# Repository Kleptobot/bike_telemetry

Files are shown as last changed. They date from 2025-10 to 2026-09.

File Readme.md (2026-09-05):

# OBike — Open Bicycle Telemetry Platform

OBike is an open-source hardware and firmware project for building a DIY bike computer that feels closer to a purpose-built cycling device than a generic microcontroller project. It combines a colour display, GPS, Bluetooth sensors, barometric altitude, and SD-card logging into a single platform you can build, modify, and improve.

If you like the idea of a compact, open bike computer that can log rides, display live metrics, and be extended with new sensors or UI ideas, this repository is a good place to start.

OBike v3 assembly

## What this project does

OBike is intended to capture and present ride data such as:

- speed and distance
- cadence and power
- heart rate
- GPS position and track history
- barometric altitude and sensor-derived data

It presents that information on a colour screen and can log sessions to microSD in FIT, TCX, or CSV formats.

It also supports common Bluetooth cycling peripherals that implement the CSC, HRM, and CPS profiles.

## What is in this repository

- `src/` — firmware source in C++
  - `src/App.*` — main application state and control flow
  - `src/HAL/` — hardware abstraction for GPS, SD, Bluetooth, buttons, and sensors
  - `src/ui/` — UI screens and widgets
  - `src/Loggers/` — FIT, TCX, and CSV logging implementations
  - `src/display/` — display driver and rendering wrappers
- `kicad/` — KiCad schematic and PCB layout files
- `3D_CAD/` — enclosure and mounting CAD files for 3D printing
- `sim/` — desktop simulator for trying the firmware logic without hardware
- `platformio.ini` — PlatformIO build configuration

## Hardware overview

The current hardware target is a compact embedded bike-computer build based on:

- MCU: Seeed Studio XIAO nRF52840 (Sense)
- GNSS: Quectel LC76G module
- Display: ST7789-based full-colour 240×320 SPI panel
- Sensors: RTC, barometric pressure sensor, IMU, and SD card storage
- IO: debounced physical controls and Bluetooth cycling-device support

## Quick start

### Build the firmware

1. Install PlatformIO.
2. From the repository root, run:

   ```bash
   platformio run
   ```

3. To upload to the target board:

   ```bash
   platformio run --target upload
   ```

### Try it without hardware

The repository includes a desktop simulator under `sim/` that can exercise much of the application logic and UI without needing the embedded board.

## Software features

- Firmware built with PlatformIO and the Arduino framework
- Telemetry aggregation from BLE sensors, GPS, and onboard sensors
- Logging to microSD in FIT, TCX, and CSV formats
- GPS control and NMEA handling for the LC76G module
- A simple UI for ride data and device interaction
- Bluetooth device discovery, pairing, and connection management

## Dependencies

The firmware depends on a number of Arduino and embedded libraries, including:

- `Adafruit_GFX`
- `Adafruit_ST7789`
- `RTClib`
- `MCP23017` support for the I/O expander
- `LSM6DS3`
- `XENSIV` pressure-sensor support
- `ArduinoJson`
- `TinyGPSPlus`

## Key files to inspect

- `src/HAL/LC76G.cpp` and `src/HAL/LC76G.hpp` — GNSS driver, NMEA handling, and command flow
- `src/display/Display.hpp` and `src/display/Display.cpp` — display wrapper and rendering layer
- `src/Loggers/TCXLogger.cpp` and `src/Loggers/CSVLogger.cpp` — ride logging implementations
- `src/App.cpp` — main application loop and state handling
- `kicad/` — schematic and PCB design files
- `3D_CAD/` — printable enclosure and mounting hardware

## Troubleshooting and debugging

- Serial logs are useful during development and can help trace GPS and device activity.
- Raw NMEA data can be captured to the SD card for debugging GPS behavior.
- The LC76G path has previously been sensitive to malformed or long NMEA streams, so keeping firmware updates current is important if you hit GPS issues.

## Notes for first-time visitors

This project is best viewed as a hands-on, open-source bike-computer platform rather than a polished consumer product. It is a strong fit if you want to learn embedded firmware, PCB design, logging formats, BLE peripherals, and how a compact cycling computer can be assembled from open parts.

If you are curious about building your own ride-data device, this repository is a practical starting point for both the hardware and software sides of the project.

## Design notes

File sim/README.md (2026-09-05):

# OBike simulator

Runs the OBike firmware on a desktop. The UI you see is drawn by the real
`Adafruit_GFX` through the real widgets — not a mock-up — so it can be used
both for UI development and for exercising application logic.

## What is real and what is simulated

Only **two** firmware translation units are replaced:

| Replaced | Why |
|---|---|
| `src/HAL/HAL.cpp` → `host/SimHAL.cpp` | supplies simulated sensor values |
| `src/HAL/LC76G.cpp` → `host/SimLC76G.cpp` | I2C GNSS transport has no meaning on a host |

Everything else is compiled from the real source and runs unmodified:

- all of `App`, `DataModel`, `Loggers`, `Map`, `Fusion` and `ui`
- `InputSystem` — including the real `button` edge/hold/repeat logic
- `Sensors`, `SDCard`, and the whole `Fusion` layer (altitude fusion, speed
  selection, grade, distance) — the simulated barometer is driven from the
  scenario altitude, so the real estimator computes what the tiles show
- the entire Bluetooth stack, **including the CSC/CPS/HRM measurement parsers**

The vendored libraries (`Adafruit_GFX`, `ArduinoJson`, `TinyGPSPlus`) are linked
straight out of `.pio/libdeps`, not copied, so the simulator cannot drift from
the firmware build.

GPS is driven by generating **real NMEA sentences** (with correct checksums) and
feeding them through the real `TinyGPSPlus`, so fix acquisition, speed and
altitude age all exercise the production code path.

## Quick start

One prerequisite: run `pio run` in the repo root once, so `.pio/libdeps` exists
— the simulator links the same library sources the firmware does.

**Windows** (cmd.exe, PowerShell, or just double-click `run.bat`):

```
cd sim
.
un.bat --headless --frames 30 --out out
python tools\ppm2png.py out --scale 2
```

Note the leading `.\` — PowerShell does not run programs from the current
directory without it. In cmd.exe plain `run.bat` is fine.

**Git Bash / Linux / macOS:**

```
cd sim
./run.sh --headless --frames 30 --out out
python3 tools/ppm2png.py out --scale 2
```

Then open `out/frame_0029.png`.

Both launchers build if needed and locate the compiler themselves, so nothing
has to be added to PATH. If you would rather drive make directly:

```
mingw32-make            # SDL window if SDL2 is available
mingw32-make headless   # force the no-SDL build
mingw32-make run
```

Note the Makefile recipes use `mkdir -p` and `rm -rf`; `run.bat` puts Git for
Windows' `usrin` on PATH so those exist under cmd.exe.

## Run

```
run.bat                                     # interactive window (needs SDL2)
run.bat --headless --frames 200 --out out   # frame dump, no dependencies
```

Frames are RGB565 PPM, which most image viewers will not open.
`tools/ppm2png.py` converts them using only `zlib` and `struct` from the
standard library, so no Pillow install is needed. `--gif out/ride.gif` also
writes an animation — that one path does want Pillow.

## Toolchain

If the launcher reports no compiler:

```
winget install BrechtSanders.WinLibs.POSIX.UCRT
```

## SDL2 (optional, for the interactive window)

```
tools\get-sdl2.bat          # Windows
tools/get-sdl2.sh           # Git Bash / Linux / macOS
```

Downloads the SDL2 MinGW SDK into `third_party/` and drops the 32-bit half,
leaving about 60 MB. **`third_party/` is gitignored** — it is a platform
specific binary SDK, and the repo links third-party sources rather than
vendoring them, the same way `Adafruit_GFX` comes from `.pio/libdeps`.

Without SDL2 the build falls back to headless automatically and still runs and
writes frames; only the window and keyboard input are missing. `SDL2.dll` is
copied next to the binary at build time, so nothing needs to be on PATH.

| Flag | Meaning |
|---|---|
| `--headless` | no window |
| `--frames N` | headless frame count |
| `--step MS` | simulated milliseconds per frame |
| `--out DIR` | write RGB565 frames as PPM |
| `--scale N` | SDL window scale |
| `--sd DIR` | SD card root (default `./sdcard`) |

Keys: arrows = D-pad, Enter/Space = select, `S` toggles the SD card, `G` toggles
the GPS fix, `[` / `]` change speed, Esc quits.

## Simulated time

`millis()` is a counter the frontend advances, not the wall clock. A headless
run is therefore fully deterministic and can be stepped in a debugger, and a
scenario can run faster than real time. `delay()` advances the counter rather
than sleeping.

## Sample card contents

`sample-sd/` holds a starting configuration, copied into `sdcard/` on first run
(never overwriting an existing one, so anything you change in the simulator
survives):

| File | What it gives you |
|---|---|
| `layout.txt` | a 2x3 tile grid: full-width Speed, then Cadence/HeartRate and Power/TotalDist |
| `bikeStats.txt` | 2105 mm wheel circumference -- without this the wheel-speed path computes exactly 0 |
| `biometrics.txt` | mass and HR zones, so the heart-rate tile colours correctly |
| `time.txt` | UTC offset 0 |

To start clean, delete `sdcard/` and run again. To keep several
configurations, copy them elsewhere and use `--sd DIR`.

## The SD card is a real directory

`./sdcard/` backs `IStorage`, so `layout.txt`, `biometrics.txt` and
`devices.txt` behave exactly as on the device — and a simulated ride writes a
genuine `.fit` file you can open in Garmin Connect, Strava or the FIT SDK.
That is a considerably stronger check on the logger than any assertion.

## Injecting BLE measurements

`Sim::buildCpsMeasurement()` and friends construct spec-shaped payloads;
`Sim::injectCpsNotification()` hands them to the real parser. Useful for
checking power/cadence decoding without a sensor.

## Simulated sensors

The sim can run the whole sensor story -- pairing, discovery, notification
decoding, baselining and the RPM smoothing filters -- with no radio:

- At init the card is seeded with a `devices.txt` fixture (three sensors:
  wheel, power, heart rate) unless one is already present, so the firmware's
  real `loadDevices()` path creates the parser devices at App BOOT.
- ~1.5 s of simulated time in, each device's real `discover()` runs against
  the stub radio and the stub connection handles are aligned.
- `HAL::update()` then feeds spec-shaped notifications into the parsers at
  the ~1 Hz cadence real sensors use, whenever the scenario says a sensor is
  present (`wheelRPMLive`, `power > 0`, `heartRate > 0`).

`--sensors` starts a headless run with all three sensors live at riding
values (24 km/h, 85 rpm, 180 W, 132 bpm). Interactively, `]` brings the
wheel sensor up as before. Values reaching the UI, the fusion engine and the
loggers have been decoded by the unmodified firmware parsers.

Note the ramp-in: the CSC parsers low-pass their revolution-derived estimates
with a ~1000-update time constant, so wheel speed and cadence climb toward
the scenario values over roughly 20-30 s of simulated time -- the same
behaviour you see on hardware after pairing. Power and heart rate decode
immediately. For a converged headless run use a longer frame count, e.g.
`--headless --sensors --frames 4000`.

## Headless navigation and telemetry

Headless runs can also navigate the UI and report what the app published:

```
./build/obike-sim --headless --sensors --stats --frames 1200 --last 2 \
                  --screen BikeStats --out out
```

- `--sensors` starts the run with all three sensors paired and live
- `--stats` prints the published telemetry every 250 frames -- a numeric
  trace of exactly what the app derived from the injected data
- `--screen NAME` navigates once boot completes (BikeStats, Settings,
  Bluetooth, Biometrics, GPS, Time, Display, UnmountSD, MainMenu)
- `--last N` writes only the final N PPM frames of the run

## Relationship to unit tests

The `stubs/` directory is the same substrate a native test build needs. A test
target reuses `stubs/` and the host `IStorage`, drops `host/main.cpp` and the
UI sources, and adds a test runner. The expensive part — the Arduino and
hardware stubs — is already done.

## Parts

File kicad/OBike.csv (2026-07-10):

Reference | Value | Footprint | MANUFACTURER | Digikey PN | Qty
C1,C3,C11,C13 | 0.1uF | Capacitor_SMD:C_0805_2012Metric | Samsung | 1276-2442-1-ND | 4
C2,C4,C5,C6,C7,C8,C9,C12,C14 | 1.0uF | Capacitor_SMD:C_0805_2012Metric | Samsung | 1276-1066-1-ND | 9
C10,C19 | 10uF | Capacitor_SMD:C_0603_1608Metric | Samsung | 1276-1038-1-ND | 2
C16,C21 | 33pF | Capacitor_SMD:C_0603_1608Metric | KEMET | 399-C0603C330K3RACTUCT-ND | 2
C17,C20 | 100nF | Capacitor_SMD:C_0603_1608Metric | KEMET | 399-C0603C104K3RACTUCT-ND | 2
C18 | 4.7uF | Capacitor_SMD:C_0603_1608Metric | Samsung | 1276-1044-1-ND | 1
D1,D2,D3,D4,D5 | 1N4148W | Diode_SMD:D_SOD-123 | SMC Diode Solutions | 1655-1N4148WCT-ND | 5
D6,D7 | ESDA051-1JY | Diode_SMD:D_SOD-323 | STMicroelectronics | 497-ESDA051-1JYCT-ND | 2
J1 | F34G-1A7Q1-E8C40 | amphenol:AMPHENOL_F34G-1A7Q1-E8C40 | Amphenol | 609-F34G-1A7Q1-E8C40CT-ND | 1
J2 | Micro_SD_Card_Det1 | CUI:CUI_MSD-4-A | Same Sky | 2223-MSD-4-ACT-ND | 1
J3 | Conn_01x02 | Connector_JST:JST_PH_S2B-PH-K_1x02_P2.00mm_Horizontal | JST | 455-1719-ND | 1
J5 | U.FL-R-SMT-1_10_ | Hirose:HRS_U.FL-R-SMT-1_10_ | Hirose | H11891CT-ND | 1
Q1,Q2 | SS8050 | Package_TO_SOT_SMD:SOT-23 | MCC | MMSS8550-H-TPMSCT-ND | 2
R1,R2,R3,R4,R5,R6,R7,R8,R9,R10,R22,R23,R24,R25 | 10K | Resistor_SMD:R_0805_2012Metric |  | RMCF0805JT10K0CT-ND | 14
R11,R16,R17 | 100K | Resistor_SMD:R_0603_1608Metric |  | RMCF0603FT100KCT-ND | 3
R12 | 2R2 | Resistor_SMD:R_0603_1608Metric |  | RMCF0603FT2R20CT-ND | 1
R15,R38 | 1K | Resistor_SMD:R_0603_1608Metric |  | RMCF0603JT1K00CT-ND | 2
R18,R37 | 10K | Resistor_SMD:R_0603_1608Metric |  | RMCF0603JT10K0CT-ND | 2
R36 | 47R | Resistor_SMD:R_0603_1608Metric |  | RMCF0805JT10K0CT-ND | 1
SW1 | 5_position_tactile | 5_pos:5-position | TE Connectivity | 450-2425755-1CT-ND | 1
U1 | DPS368XTSA1 | Infineon Technologies:PG-VLGA-8-2_INF | Infineon Technologies | DPS368XTSA1CT-ND | 1
U2 | DS3231M | Package_SO:SOIC-8_3.9x4.9mm_P1.27mm | Analog Devices Inc | DS3231MZ+-ND | 1
U3 | MCP23017_SO | Package_SO:SOIC-28W_7.5x17.9mm_P1.27mm | Microchip | MCP23017T-E/SOCT-ND | 1
U4 | 74HC14 | Package_SO:SOIC-14_3.9x8.7mm_P1.27mm | Toshiba Semiconductor | 74HC14DCT-ND | 1
U6,U8,U10 | MAX40200AUK | Package_TO_SOT_SMD:SOT-23-5 | Analog Devices Inc | MAX40200AUK+TCT-ND | 3
U7 | LC76G | quectel:XCVR_LC76G | Quectel | 2958-LC76GPAMDCT-ND | 1
U9 | W25N01GVZEIG_TR | windbond:SON127P800X600X80-9N | Winbond Electronics | 256-W25N01GVZEIGTRCT-ND | 1
LS1 | ASI09N40MTRQ | Mallory:ASI09N40M | Mallory | 458-ASI09N40MTRQCT-ND | 1

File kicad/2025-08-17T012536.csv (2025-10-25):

Index | Quantity | Part Number | Manufacturer Part Number | Description | Customer Reference | Available | Backorder | Unit Price | Extended Price AUD
1 | 10 | 1276-1038-1-ND | CL10A106KQ8NNNC | CAP CER 10UF 6.3V X5R 0603 |  | 10 | 0 | 0.03800 | 0.38
2 | 10 | 399-C0603C330K3RACTUCT-ND | C0603C330K3RACTU | CAP CER 33PF 25V X7R 0603 |  | 10 | 0 | 0.20500 | 2.05
3 | 10 | 399-C0603C104K3RACTUCT-ND | C0603C104K3RACTU | CAP CER 0.1UF 25V X7R 0603 |  | 10 | 0 | 0.04100 | 0.41
4 | 15 | 1655-1N4148WCT-ND | 1N4148W | DIODE GEN PURP 75V 250MA SOD123 |  | 15 | 0 | 0.12300 | 1.85
5 | 10 | 1727-2742-1-ND | PTVS5V0Z1USKYL | TVS DIODE 5VWM 12VC DSN1608-2 |  | 10 | 0 | 0.11100 | 1.11
6 | 3 | 609-1200-1-ND | 62684-402100ALF | CONN FPC TOP 40POS 0.5MM R/A |  | 3 | 0 | 0.95000 | 2.85
7 | 3 | 2223-MSD-4-ACT-ND | MSD-4-A | CONN MICROSD CARD R/A SMD |  | 3 | 0 | 0.57000 | 1.71
8 | 3 | H11891CT-ND | U.FL-R-SMT-1(10) | CONN U.FL RCPT STR 50 OHM SMD |  | 3 | 0 | 1.91000 | 5.73
9 | 50 | RMCF0603FT100KCT-ND | RMCF0603FT100K | RES 100K OHM 1% 1/10W 0603 |  | 50 | 0 | 0.01820 | 0.91
10 | 50 | RMCF0603FT2R20CT-ND | RMCF0603FT2R20 | RES 2.2 OHM 1% 1/10W 0603 |  | 50 | 0 | 0.01020 | 0.51
11 | 2 | 2958-LC76GPAMDCT-ND | LC76GPAMD | RF TXRX MODULE NAVIGATION SMD |  | 2 | 0 | 13.18000 | 26.36
12 | 2 | 256-W25N01GVZEIGTRCT-ND | W25N01GVZEIG TR | IC FLASH 1GBIT SPI 104MHZ 8WSON |  | 2 | 0 | 5.76000 | 11.52
13 | 3 | MAX40200AUK+TCT-ND | MAX40200AUK+T | IC DIODE CURRENT SWITCH SOT23-5 |  | 3 | 0 | 2.04000 | 6.12
14 | 10 | 1276-1044-1-ND | CL10A475KP8NNNC | CAP CER 4.7UF 10V X5R 0603 |  | 10 | 0 | 0.01000 | 0.10

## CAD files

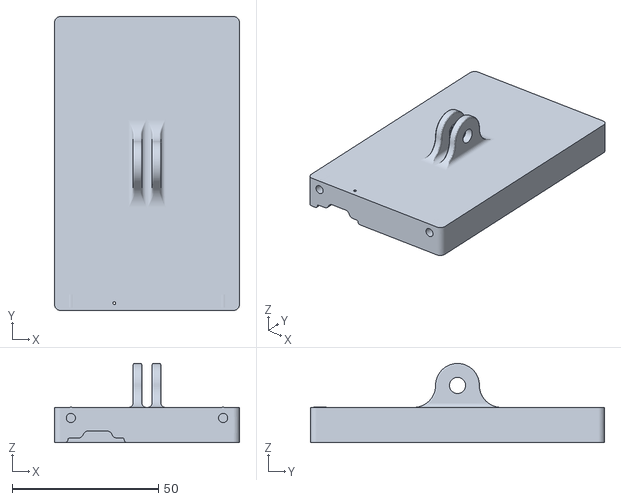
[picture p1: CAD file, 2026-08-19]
3D_CAD/back_retainer_combo.stl
63.2 x 100.4 x 27.0

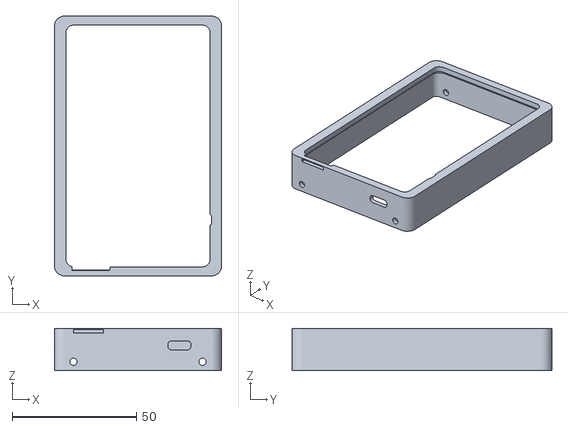
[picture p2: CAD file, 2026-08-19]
3D_CAD/housing.stl
67.4 x 104.6 x 16.9

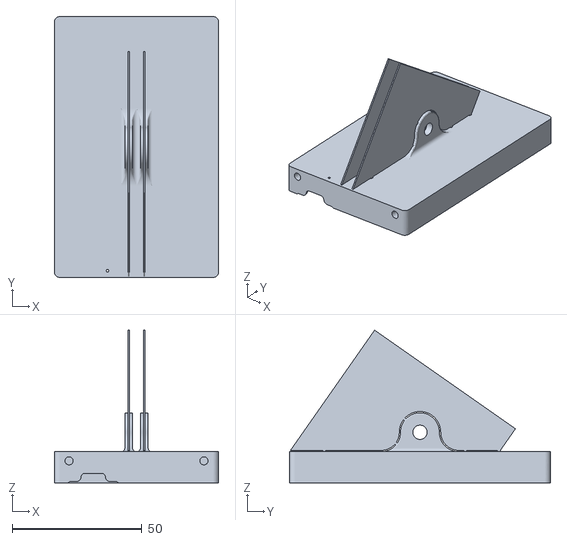
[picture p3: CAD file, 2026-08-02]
3D_CAD/back_retainer_combo + support.stl
63.4 x 100.7 x 58.9

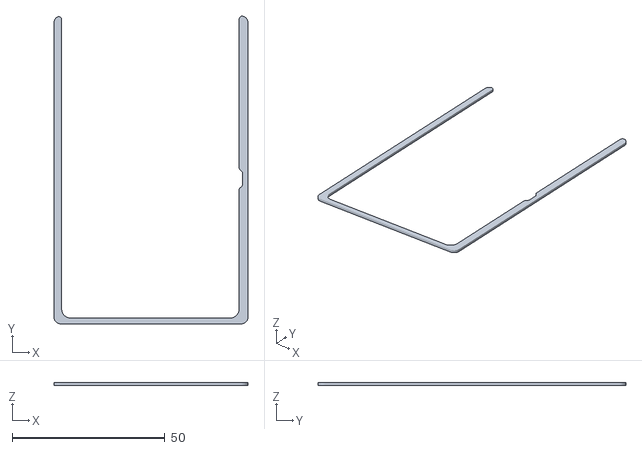
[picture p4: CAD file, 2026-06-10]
3D_CAD/shim.stl
63.4 x 100.6 x 1.00

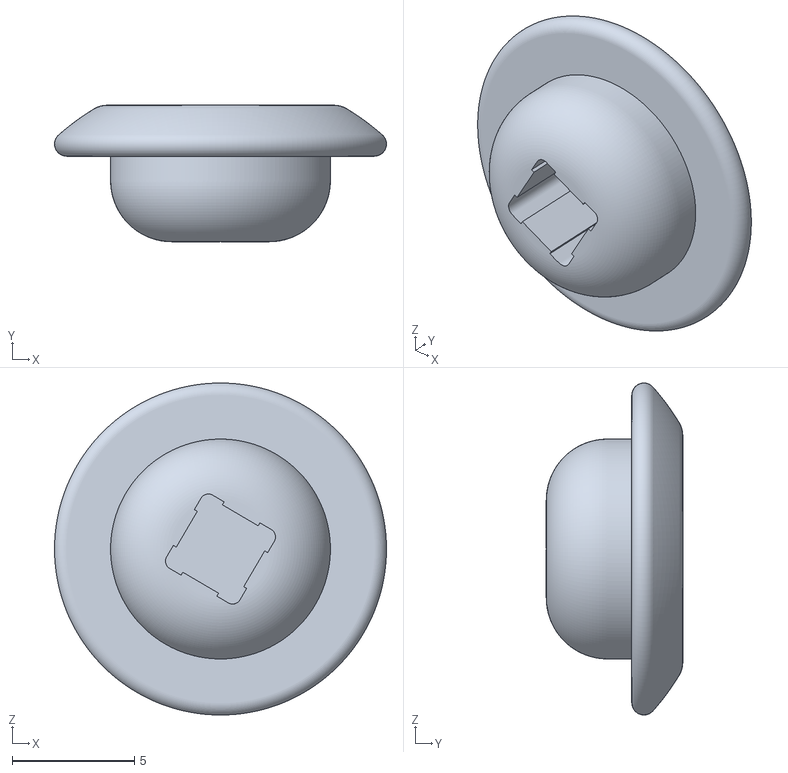
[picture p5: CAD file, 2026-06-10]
3D_CAD/nubbin.stl
13.6 x 5.59 x 13.6

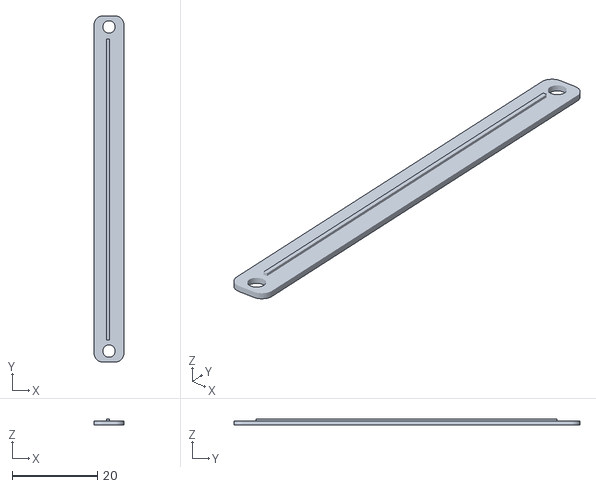
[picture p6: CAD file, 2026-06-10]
3D_CAD/battery_strap.stl
7.00 x 81.3 x 1.50

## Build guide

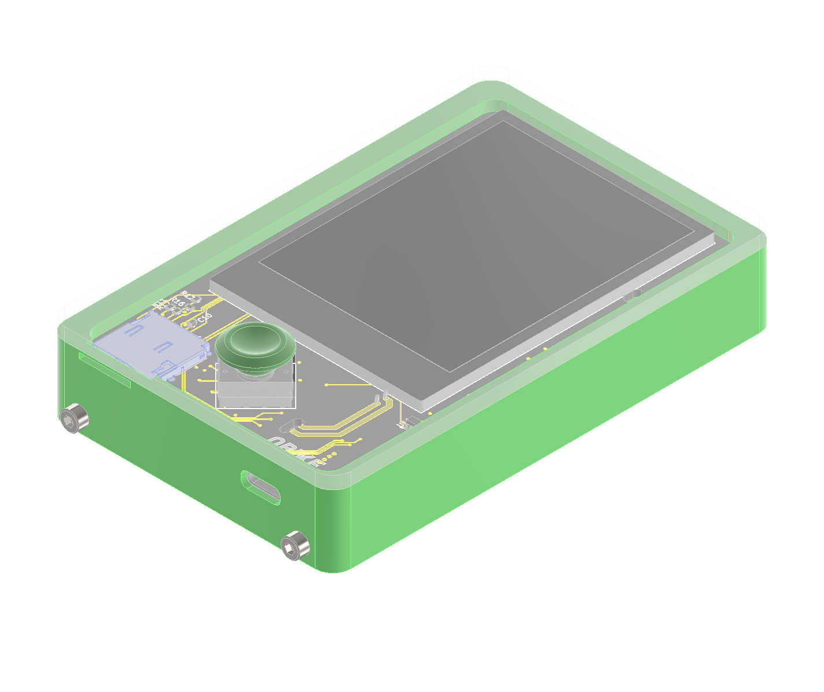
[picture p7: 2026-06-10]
3D_CAD/OBike v3 assembly.png

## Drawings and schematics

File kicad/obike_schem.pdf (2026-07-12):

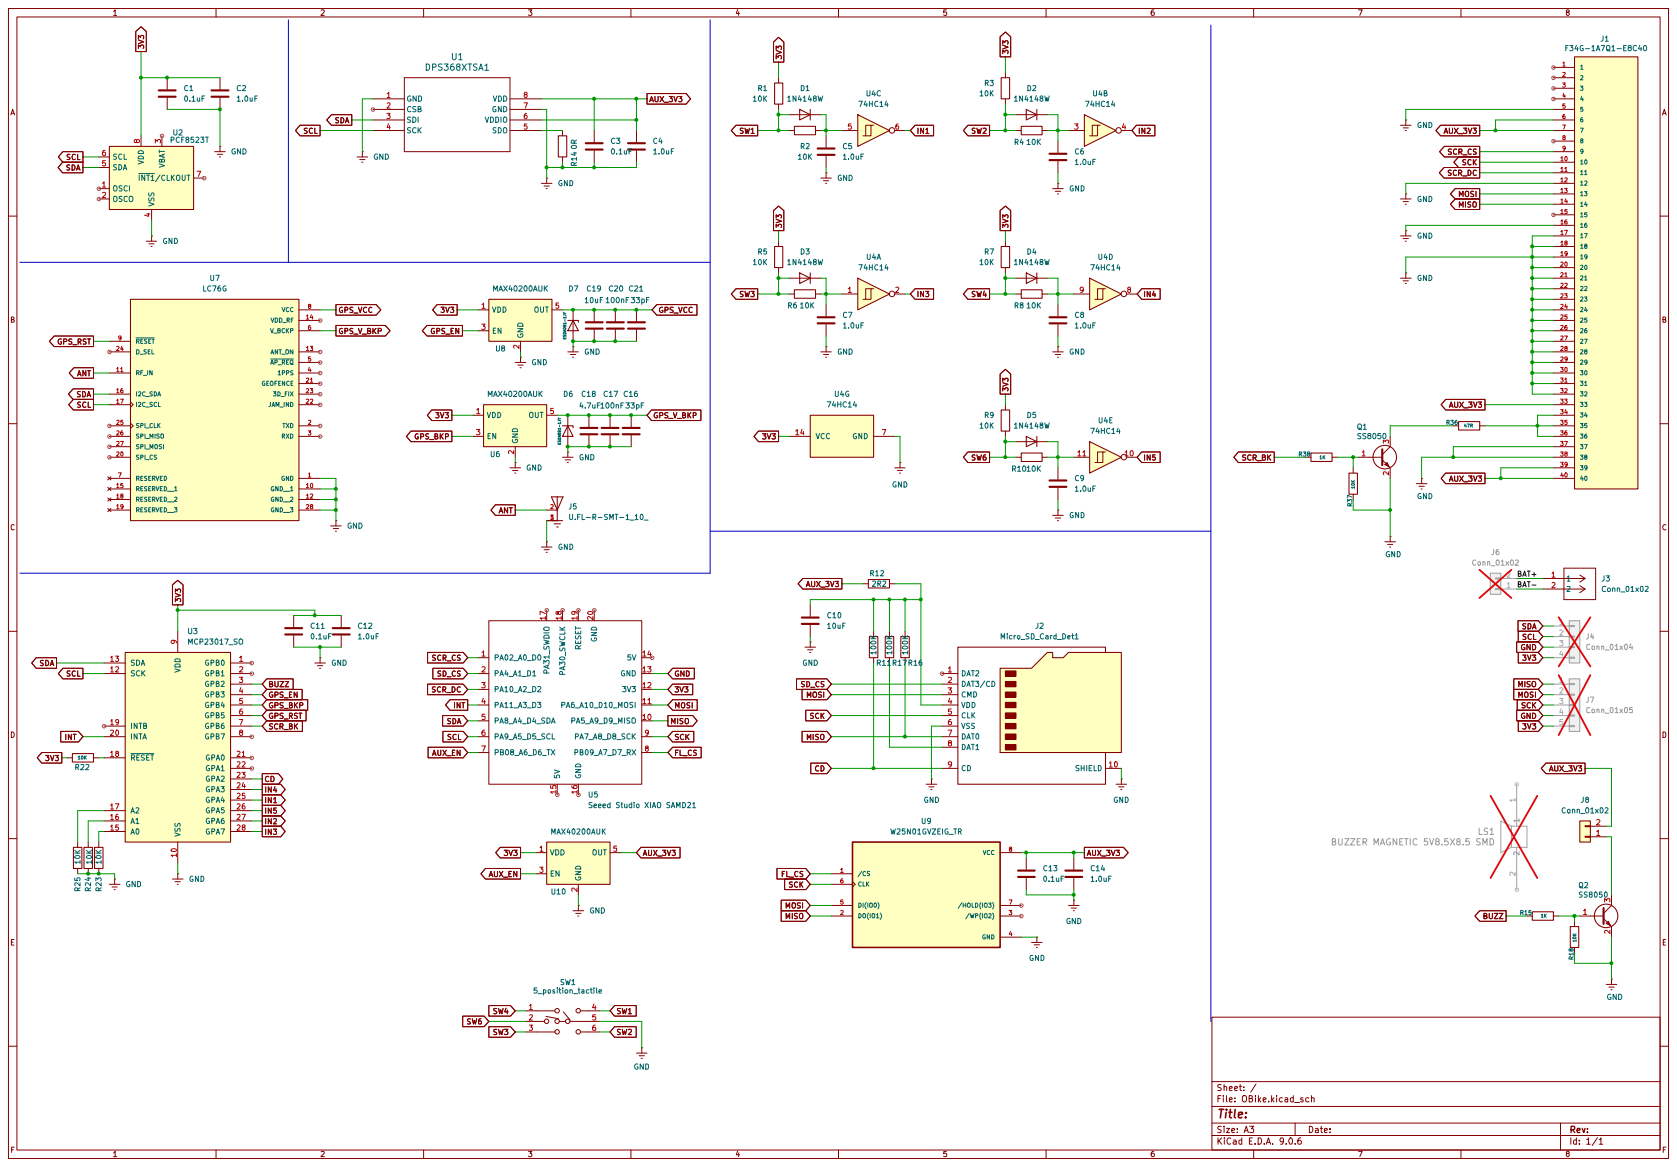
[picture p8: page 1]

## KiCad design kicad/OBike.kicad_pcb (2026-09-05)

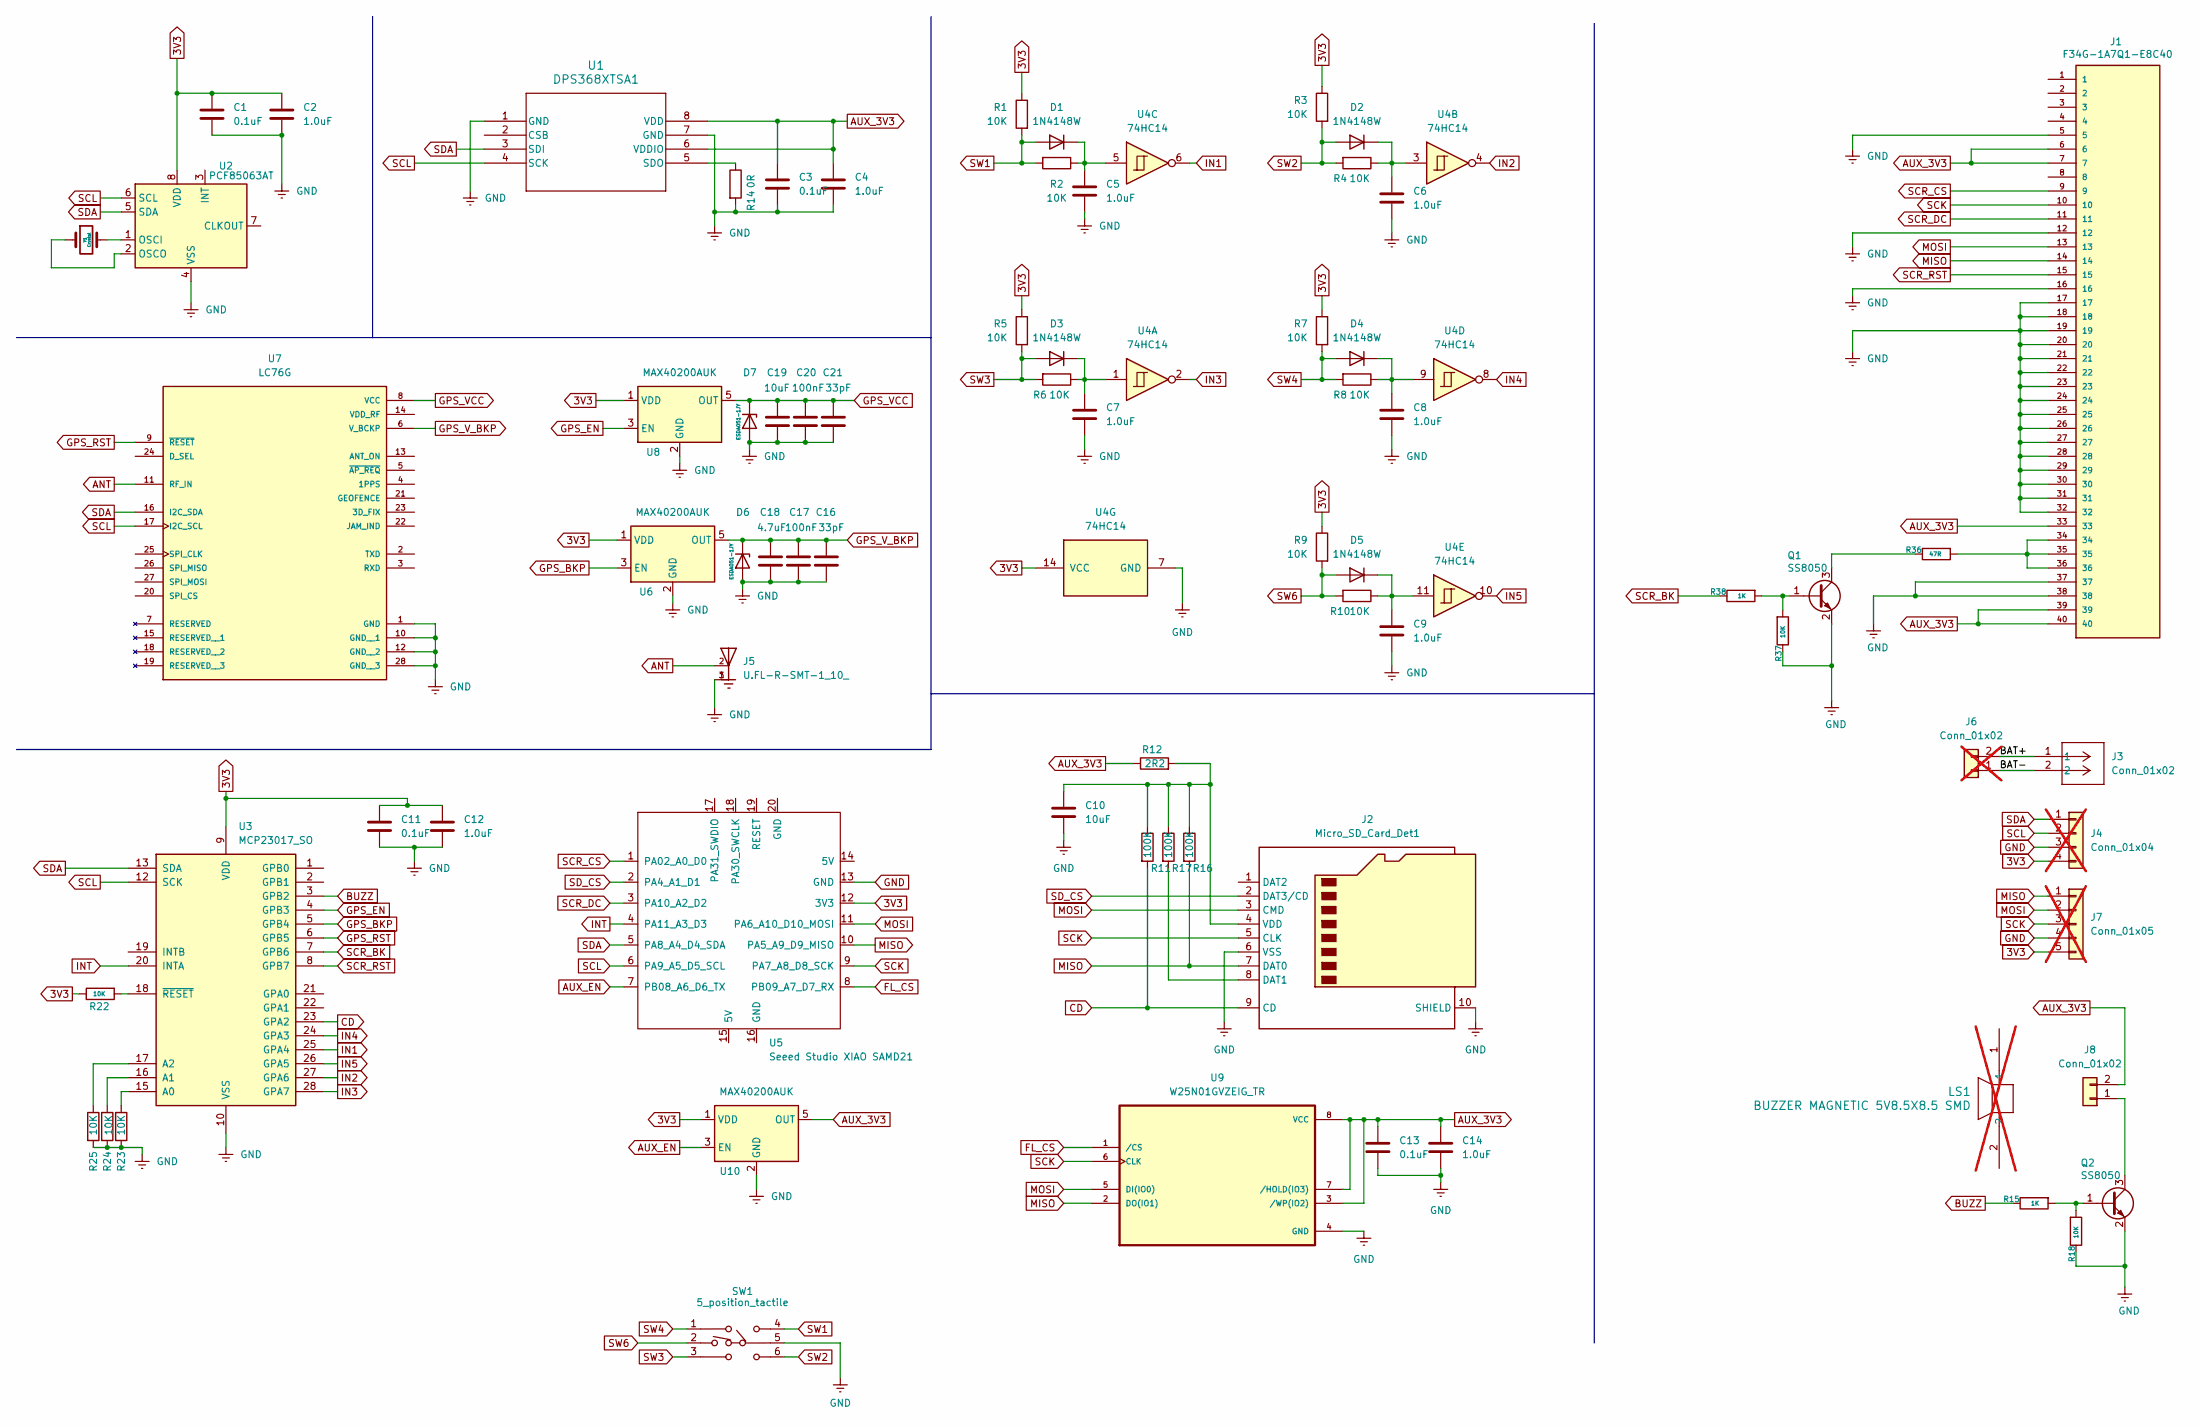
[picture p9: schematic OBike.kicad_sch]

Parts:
C1, C3, C11, C13: 0.1uF; C_0805_2012Metric; Digikey PN 1276-2442-1-ND
C2, C4, C5, C6, C7, C8, C9, C12, C14: 1.0uF; C_0805_2012Metric; Digikey PN 1276-1066-1-ND
C10, C19: 10uF; C_0603_1608Metric; Digikey PN 1276-1038-1-ND
C16, C21: 33pF; C_0603_1608Metric; Digikey PN 399-C0603C330K3RACTUCT-ND
C17, C20: 100nF; C_0603_1608Metric; Digikey PN 399-C0603C104K3RACTUCT-ND
C18: 4.7uF; C_0603_1608Metric; Digikey PN 1276-1044-1-ND
D1, D2, D3, D4, D5: 1N4148W; D_SOD-123; Manufacturer PN 1N4148W RHG; Digikey PN 1655-1N4148WCT-ND
D6, D7: ESDA051-1JY; D_SOD-323; Digikey PN 497-ESDA051-1JYCT-ND
J1: F34G-1A7Q1-E8C40; AMPHENOL_F34G-1A7Q1-E8C40; PARTREV A; Digikey PN 609-F34G-1A7Q1-E8C40CT-ND
J2: Micro_SD_Card_Det1; CUI_MSD-4-A; Manufacturer PN MSD-4-A; Digikey PN 2223-MSD-4-ACT-ND
J3: Conn_01x02; JST_PH_S2B-PH-K_1x02_P2.00mm_Horizontal; Manufacturer PN CONN HEADER R/A 2POS 2MM; Digikey PN 455-1719-ND
J4: Conn_01x04; PinHeader_1x04_P2.54mm_Vertical; not fitted
J5: U.FL-R-SMT-1_10_; HRS_U.FL-R-SMT-1_10_; Digikey PN H11891CT-ND
J6: Conn_01x02; PinHeader_1x02_P2.00mm_Vertical; not fitted
J7: Conn_01x05; PinHeader_1x05_P2.54mm_Vertical; not fitted
J8: Conn_01x02; PinHeader_1x02_P2.00mm_Vertical
LS1: BUZZER MAGNETIC 5V8.5X8.5 SMD; CUI_CMT-8540S-SMT; Digikey PN 102-3746-1-ND; not fitted
Q1, Q2: SS8050; SOT-23; Digikey PN MMSS8050-H-TPMSCT-ND
R1, R2, R3, R4, R5, R6, R7, R8, R9, R10, R22, R23, R24, R25: 10K; R_0805_2012Metric; Digikey PN RMCF0805JT10K0CT-ND
R11, R16, R17: 100K; R_0603_1608Metric; Digikey PN RMCF0603FT100KCT-ND
R12: 2R2; R_0603_1608Metric; Digikey PN RMCF0603FT2R20CT-ND
R14: 0R; R_0603_1608Metric
R15, R38: 1K; R_0603_1608Metric; Digikey PN RMCF0603JT1K00CT-ND
R18, R37: 10K; R_0603_1608Metric; Digikey PN RMCF0603JT10K0CT-ND
R36: 47R; R_0603_1608Metric; Digikey PN RMCF0603JT47R0CT-ND
SW1: 5_position_tactile; 5-position; Manufacturer PN 2425755-1; Digikey PN 450-2425755-1CT-ND
U1: DPS368XTSA1; PG-VLGA-8-2_INF; Manufacturer PN DPS368XTSA1; Digikey PN DPS368XTSA1CT-ND
U2: PCF85063AT; SOIC-8_3.9x4.9mm_P1.27mm; Digikey PN 568-12403-1-ND
U3: MCP23017_SO; SOIC-28W_7.5x17.9mm_P1.27mm; Manufacturer PN MCP23017T-E/SO; Digikey PN MCP23017T-E/SOCT-ND
U4: 74HC14; SOIC-14_3.9x8.7mm_P1.27mm; Manufacturer PN 74HC14D; Digikey PN 74HC14DCT-ND
U5: Seeed Studio XIAO SAMD21; XIAO-nRF52840-Sense-14P-2.54-21X17.8MM
U6, U8, U10: MAX40200AUK; SOT-23-5; Digikey PN MAX40200AUK+TCT-ND
U7: LC76G; XCVR_LC76G; PARTREV 1.0; Digikey PN 2958-LC76GPAMDCT-ND
U9: W25N01GVZEIG_TR; SON127P800X600X80-9N; Digikey PN 256-W25N01GVZEIGTRCT-ND
Y1: Crystal; OSCSC320X150X90; Digikey PN 1908-Q0,032768-JTX310-7-20-T3-80K-LFCT-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

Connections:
3V3: C1.1, C2.1, C11.1, C12.1, J4.4, J7.5, R1.1, R3.1, R5.1, R7.1, R9.1, R22.1, U2.8 (VDD), U3.9 (VDD), U4.14 (VCC), U5.12 (3V3), U6.1 (VDD), U8.1 (VDD), U10.1 (VDD)
/BAT+: J3.1, J6.2
/BAT-: J3.2, J6.1
ANT: J5.2, U7.11 (RF_IN)
AUX_3V3: C3.1, C4.1, C13.1, C14.1, J1.6, J1.7, J1.33, J1.39, J1.40, J8.2, R12.1, U1.6 (VDDIO), U1.8 (VDD), U9.3 (/WP(IO2)), U9.7 (/HOLD(IO3)), U9.8 (VCC), U10.5 (OUT)
AUX_EN: U5.7 (PB08_A6_D6_TX), U10.3 (EN)
BUZZ: R15.1, U3.3 (GPB2)
CD: J2.9 (CD), R11.2, U3.23 (GPA2)
FL_CS: U5.8 (PB09_A7_D7_RX), U9.1 (/CS)
GND: C1.2, C2.2, C3.2, C4.2, C5.2, C6.2, C7.2, C8.2, C9.2, C10.2, C11.2, C12.2, C13.2, C14.2, C16.2, C17.2, C18.2, C19.2, C20.2, C21.2, D6.2 (A), D7.2 (A), J1.5, J1.12, J1.16, J1.17, J1.18, J1.19, J1.20, J1.21, J1.22, J1.23, J1.24, J1.25, J1.26, J1.27, J1.28, J1.29, J1.30, J1.31, J1.32, J1.37, J1.38, J2.6 (VSS), J2.10 (SHIELD), J4.3, J5.1, J5.3, J7.4, Q1.2 (E), Q2.2 (E), R14.2, R18.1, R23.2, R24.2, R25.2, R37.1, SW1.5 (E), U1.1 (GND), U1.7 (GND), U2.4 (VSS), U3.10 (VSS), U4.7 (GND), U5.13 (GND), U6.2 (GND), U7.1 (GND), U7.10 (GND__1), U7.12 (GND__2), U7.28 (GND__3), U8.2 (GND), U9.4 (GND), U10.2 (GND)
GPS_BKP: U3.5 (GPB4), U6.3 (EN)
GPS_EN: U3.4 (GPB3), U8.3 (EN)
GPS_RST: U3.6 (GPB5), U7.9 (~RESET)
GPS_VCC: C19.1, C20.1, C21.1, D7.1 (K), U7.8 (VCC), U8.5 (OUT)
GPS_V_BKP: C16.1, C17.1, C18.1, D6.1 (K), U6.5 (OUT), U7.6 (V_BCKP)
IN1: U3.25 (GPA4), U4.6
IN2: U3.27 (GPA6), U4.4
IN3: U3.28 (GPA7), U4.2
IN4: U3.24 (GPA3), U4.8
IN5: U3.26 (GPA5), U4.10
INT: U3.20 (INTA), U5.4 (PA11_A3_D3)
MISO: J1.14, J2.7 (DAT0), J7.1, R16.2, U5.10 (PA5_A9_D9_MISO), U9.2 (DO(IO1))
MOSI: J1.13, J2.3 (CMD), J7.2, U5.11 (PA6_A10_D10_MOSI), U9.5 (DI(IO0))
unnamed: C5.1, D1.1 (K), R2.1, U4.5
unnamed: C6.1, D2.1 (K), R4.1, U4.3
unnamed: C7.1, D3.1 (K), R6.1, U4.1
unnamed: C8.1, D4.1 (K), R8.1, U4.9
unnamed: C9.1, D5.1 (K), R10.1, U4.11
unnamed: J1.34, J1.35, J1.36, R36.2
unnamed: J2.8 (DAT1), R17.2
unnamed: C10.1, J2.4 (VDD), R11.1, R12.2, R16.1, R17.1
unnamed: J8.1, Q2.3 (C)
unnamed: Q1.1 (B), R37.2, R38.2
unnamed: Q1.3 (C), R36.1
unnamed: Q2.1 (B), R15.2, R18.2
unnamed: R14.1, U1.5 (SDO)
unnamed: U2.1 (OSCI), Y1.2
unnamed: U2.2 (OSCO), Y1.1
unnamed: R23.1, U3.15 (A0)
unnamed: R24.1, U3.16 (A1)
unnamed: R25.1, U3.17 (A2)
unnamed: R22.2, U3.18 (~RESET)
SCK: J1.10, J2.5 (CLK), J7.3, U5.9 (PA7_A8_D8_SCK), U9.6 (CLK)
SCL: J4.2, U1.4 (SCK), U2.6 (SCL), U3.12 (SCK), U5.6 (PA9_A5_D5_SCL), U7.17 (I2C_SCL)
SCR_BK: R38.1, U3.7 (GPB6)
SCR_CS: J1.9, U5.1 (PA02_A0_D0)
SCR_DC: J1.11, U5.3 (PA10_A2_D2)
SCR_RST: J1.15, U3.8 (GPB7)
SDA: J4.1, U1.3 (SDI), U2.5 (SDA), U3.13 (SDA), U5.5 (PA8_A4_D4_SDA), U7.16 (I2C_SDA)
SD_CS: J2.2 (DAT3/CD), U5.2 (PA4_A1_D1)
SW1: D1.2 (A), R1.2, R2.2, SW1.4 (D)
SW2: D2.2 (A), R3.2, R4.2, SW1.6 (F)
SW3: D3.2 (A), R5.2, R6.2, SW1.3 (C)
SW4: D4.2 (A), R7.2, R8.2, SW1.1 (A)
SW6: D5.2 (A), R9.2, R10.2, SW1.2 (B)

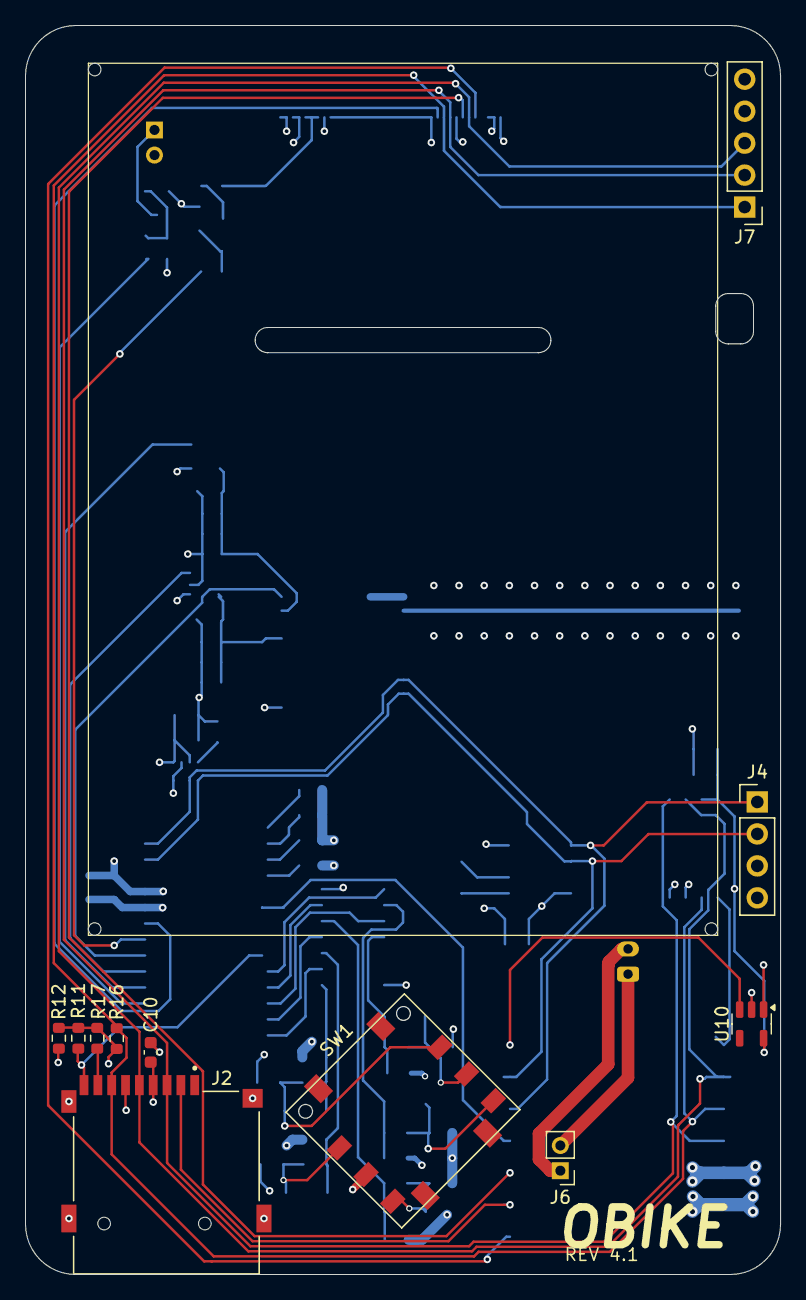
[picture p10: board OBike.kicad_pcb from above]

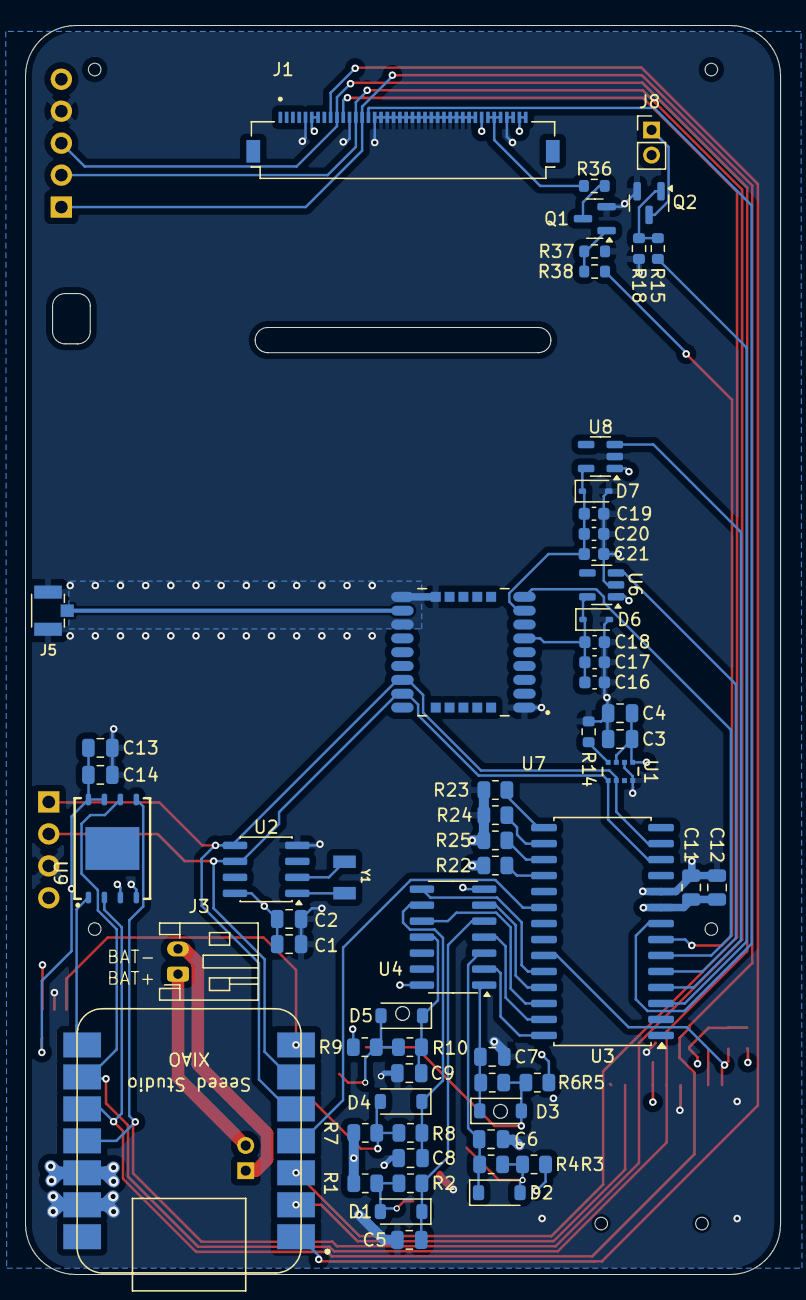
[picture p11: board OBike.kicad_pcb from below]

Board: 4 copper layers, 60.0 x 99.2 mm, 73 parts (62 on the bottom side), 55 nets.

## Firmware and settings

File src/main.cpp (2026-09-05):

#define DEBUG_INVALIDATE 0
#define DEBUG_GPS 0
#define DEBUG_INPUTS 0
#define DEBUG_BLUETOOTH 0
#define DEBUG_I2C 1

#include <Arduino.h>
#include "DebugConfig.hpp"
#include "HAL/HAL.hpp"
#include "App.hpp"

const bool ENABLE_INVALIDATE_DEBUG = DEBUG_INVALIDATE;
const bool ENABLE_GPS_DEBUG = DEBUG_GPS;
const bool ENABLE_INPUTS_DEBUG = DEBUG_INPUTS;
const bool ENABLE_BLUETOOTH_DEBUG = DEBUG_BLUETOOTH;
const bool ENABLE_I2C_DEBUG = DEBUG_I2C;

bool started = false;

void setup() {
    //run the bare minimum init, GPIO and RTC
    HAL::inst().init_low();
}

uint32_t gpsLastEnableTime = millis();
void loop() {
    __NOP();
    if (!started) {
        Serial.begin(115200);
        delay(500);
        
        HAL::inst().init(&App::instance().getModel().time().get());
        App::instance().begin(HAL::inst().SD());
        started = true;
        Serial.println("App started");
        Serial.printf("Free heap: %d bytes\n", dbgHeapTotal() - dbgHeapUsed());
        Serial.println("SD card det state: " + String(HAL::inst().inputs().SD_Det.state));
        
    }

    //update the HAL and App
    HAL::inst().update();
    App::instance().update();

    // read the state of the gps enable pin, if its low then sleep
    if ( !App::instance().getGpsEnableState() ) {
        if ((millis() - gpsLastEnableTime) > 500) { //small debounce
            NRF_POWER->SYSTEMOFF = 1;
        }
    } else {
        gpsLastEnableTime = millis();
    }
}

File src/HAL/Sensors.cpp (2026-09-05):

#include "Sensors.hpp"

namespace {
    // Observed interval between consecutive accepted samples, clamped into
    // uint16 milliseconds. A 0 result means "not yet known" (first sample,
    // or a clock that has not advanced since the previous one).
    inline uint16_t observedDt(uint32_t nowMs, uint32_t prevMs) {
        if (prevMs == 0 || nowMs <= prevMs) return 0;
        const uint32_t dt = nowMs - prevMs;
        return dt > 65000 ? 65000u : (uint16_t)dt;
    }
}

void SensorSystem::init_low() {
    _rtc.begin();
    _rtc.bit_op8(0x00, ~0x01, 0x01);

    Serial.println("RTC initialised");
    
    pinMode(VBAT_ENABLE, OUTPUT);
    pinMode(BAT_CHARGE_STATE, INPUT);

    digitalWrite(BAT_HIGH_CHARGE, HIGH); // charge with 50mA
}

void SensorSystem::init() {
    if (_myIMU->begin() != 0) {
        Serial.println("IMU init error");
    } else {
        Serial.println("IMU initialised");
    }
    
    _dps.begin(Wire);
    int16_t temp_mr = 2;
    int16_t temp_osr = 2;
    int16_t prs_mr = 2;
    int16_t prs_osr = 2;
    _dps.startMeasureBothCont(temp_mr, temp_osr, prs_mr, prs_osr);
    lastBATTime = millis() - BAT_Read_Period;
}

bool SensorSystem::update(bool i2cBusy) {
    
    int16_t ret;
    // getContResults() drains the ENTIRE DPS FIFO and treats the count
    // parameters as OUTPUTS only: the write bound is DPS__FIFO_SIZE (32),
    // never the arrays passed in. Buffers smaller than that are a stack
    // overflow waiting for a busy FIFO -- the previous 20-element buffers
    // were already latent (32 > 20), and shrinking them to 5 caused
    // hard-fault resets on every DPS pass. Size to what the library can
    // actually write.
    //
    // The bus-time lever is the poll period, not the buffer: results
    // accumulate at the DPS output rate, so a DPS_Read_Period of 5000 ms
    // drains ~10 results (~20 transactions) per pass, and polling faster
    // shrinks each pass further.
    uint8_t pressureCount = DPS__FIFO_SIZE;
    float pressure[pressureCount];
    uint8_t temperatureCount = DPS__FIFO_SIZE;
    float temperature[temperatureCount];
    bool update = false;

    if ((millis() - lastRTCTime > RTC_Read_Period) && !i2cBusy) {
        if (_setTime) {
            _setTime = false;
            _rtc.set(&_newDate);
        }
        #if DS3231
            _f32_RTC_Temp = _rtc.getTemperature();
        #endif
        dps_dat.f32_RTC_Temp = _f32_RTC_Temp;
        _now = _rtc.time(NULL);

        const uint32_t nowMs = millis();
        _rtcDtMs = observedDt(nowMs, lastRTCTime);
        lastRTCTime = nowMs;
        ++_rtcSeq;
        update = true;
    }
    if ((millis() - lastDSPTime > DPS_Read_Period) && !i2cBusy) {

        ret = _dps.getContResults(temperature, temperatureCount, pressure, pressureCount);
        //_dps.measureTempOnce(f32_DSP_Temp, 7);
        //_dps.measurePressureOnce(f32_DSP_Pa, 7);
        if (ret != 0)
        {
            // Serial.print("FAIL! ret = ");
            _dpsValid = false;
        }
        else
        {
            dps_dat.f32_DSP_Temp=0;
            for (int16_t i = 0; i < temperatureCount; i++)
            {
            dps_dat.f32_DSP_Temp+=temperature[i];
            }
            dps_dat.f32_DSP_Temp = dps_dat.f32_DSP_Temp/(float)temperatureCount;

            dps_dat.f32_DSP_Pa=0;
            for (int16_t i = 0; i < pressureCount; i++)
            {
            dps_dat.f32_DSP_Pa+=pressure[i];
            }
            dps_dat.f32_DSP_Pa = dps_dat.f32_DSP_Pa/(float)pressureCount;
            _dpsValid = true;

            // Frame stamping: only successful fetches count as samples, so
            // the interval is success-to-success rather than attempt-to-attempt.
            const uint32_t nowMs = millis();
            _dpsDtMs = observedDt(nowMs, _dpsOkTime);
            _dpsOkTime = nowMs;
            ++_dpsSeq;
        }
        dps_dat.dpsValid = _dpsValid;
        if (dpsCallback) {
            dpsCallback({dps_dat});
        }
        update = true;
        lastDSPTime = millis();    
    }
    if ((millis() - lastIMUTime > IMU_Read_Period) && !i2cBusy) {
        // One 12-byte burst over the contiguous output registers
        // (OUTX_L_G 0x22 .. OUTZ_H_XL 0x2D) replaces six separate per-axis
        // reads: 2 bus transactions instead of 12, and all six axes carry a
        // single sample instant, which is what the fusion engine wants.
        // calc*() applies exactly the scaling readFloat*() used.
        uint8_t raw[12];
        if (_myIMU->readRegisterRegion(raw, LSM6DS3_ACC_GYRO_OUTX_L_G, sizeof(raw)) != IMU_SUCCESS) {
            // Failed read: skip the sample entirely -- no stamping, no
            // callback -- mirroring how a failed DPS fetch is handled.
        } else {
            // LSB-first 16-bit pairs: gyro block first, then accel block
            // (the same layout readRawGyro*/readRawAccel* decode).
            _imu.f32_gyro_x = _myIMU->calcGyro((int16_t)(raw[0]  | (raw[1]  << 8)));
            _imu.f32_gyro_y = _myIMU->calcGyro((int16_t)(raw[2]  | (raw[3]  << 8)));
            _imu.f32_gyro_z = _myIMU->calcGyro((int16_t)(raw[4]  | (raw[5]  << 8)));
            _imu.f32_acc_x  = _myIMU->calcAccel((int16_t)(raw[6]  | (raw[7]  << 8)));
            _imu.f32_acc_y  = _myIMU->calcAccel((int16_t)(raw[8]  | (raw[9]  << 8)));
            _imu.f32_acc_z  = _myIMU->calcAccel((int16_t)(raw[10] | (raw[11] << 8)));
            const uint32_t nowMs = millis();
            _imuDtMs = observedDt(nowMs, lastIMUTime);
            lastIMUTime = nowMs;
            ++_imuSeq;
            update = true;
            if (imuCallback) {
                imuCallback({_imu.f32_acc_z,true});
            }
        }
    }
    if (millis() - lastBATTime > BAT_Read_Period) {
        //get BAT data
        digitalWrite(VBAT_ENABLE, LOW);

        uint32_t adcCount = analogRead(PIN_VBAT);
        float adcVoltage = adcCount * VBAT_MV_PER_LBS;
        float vBat = adcVoltage * (1510.0 / 510.0);

        digitalWrite(VBAT_ENABLE, HIGH);
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

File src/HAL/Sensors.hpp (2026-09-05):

#ifndef SENSORS_H
#define SENSORS_H

#include <Arduino.h>
#include <Dps3xx.h>
#include <LSM6DS3.h>
#include <functional>
#include "SensorData.hpp"
#if DS3231
    #include <RTClib.h>
#else
    #include <PCF85063A.h>
    #include <time.h>
#endif

#define LSM6DS3_ADDR 0x6A //I2C device address 0x6A
#define BAT_HIGH_CHARGE 22  // HIGH for 50mA, LOW for 100mA
#define BAT_CHARGE_STATE 23 // LOW for charging, HIGH not charging

// Volts per ADC least-significant bit, at the default 10-bit resolution and
// 3.6 V reference. (The name says MV/LBS; it is neither millivolts nor LBS.
// Left as-is to avoid churn -- see the cleanup PR.)
#define VBAT_MV_PER_LBS (0.003395996F)

// Usable terminal-voltage range of the LiPo cell, used to scale the reported
// battery percentage. 3.30 V is a conservative empty point that leaves margin
// above the protection cutoff.
#define BAT_FULL_V  (4.20F)
#define BAT_EMPTY_V (3.30F)

#define DS3231 false

class SensorSystem {
public:
    SensorSystem() {
        _myIMU = new LSM6DS3(I2C_MODE, LSM6DS3_ADDR); 
        _dps = Dps3xx();
    }
    void init_low();
    void init();
    bool update(bool i2cBusy);

    #if DS3231
        RTC_DS3231* RTC() {return &_rtc;}
    #else
        const PCF85063A & RTC() {return _rtc;}
    #endif
    
    time_t now() const {return _now;}
    int16_t batt() const {return _nBattPercentage;}
    imu_data imu() const {return _imu;}
    dps_data dps() const {return dps_dat;}
    void setTime(struct tm date);

    using DPSCallback = std::function<void(dps_data dps)>;
    using IMUCallback = std::function<void(data_record f32_acc_z)>;

    void onDPS(DPSCallback cb) { dpsCallback = cb; }
    void onIMU(IMUCallback cb) { imuCallback = cb; }

    // --- Measurement-frame stamping (see HAL/Measurements.hpp) --------------
    // Timestamps reuse the existing per-block read times; sequence numbers
    // count accepted samples; observed intervals are the time between
    // consecutive accepted samples (0 = not yet known). Pure bookkeeping:
    // no existing behaviour reads or changes because of these.
    uint32_t imuTsMs()  const { return lastIMUTime; }
    uint16_t imuSeq()   const { return _imuSeq; }
    uint16_t imuDtMs()  const { return _imuDtMs; }

    uint32_t dpsTsMs()  const { return _dpsOkTime; }   // last SUCCESSFUL fetch; lastDSPTime tracks attempts
    uint16_t dpsSeq()   const { return _dpsSeq; }
    uint16_t dpsDtMs()  const { return _dpsDtMs; }

    uint32_t rtcTsMs()  const { return lastRTCTime; }
    uint16_t rtcSeq()   const { return _rtcSeq; }
    uint16_t rtcDtMs()  const { return _rtcDtMs; }

    uint32_t battTsMs() const { return lastBATTime; }
    uint16_t battSeq()  const { return _batSeq; }
    uint16_t battDtMs() const { return _batDtMs; }

    // Promoted from a discarded local in update(): the gauge percentage is
    // derived from this voltage, which is the actual measurement.
    float vbatVolts() const { return _vBatVolts; }
    bool  charging()  const { return _charging; }

private:
    static const uint16_t BAT_Read_Period = 29999;
    // Step 5 ramp increment 1 (was 1000). Judged by the [i2c] summary:
    // bp must stay ~0, err flat, and the vario/grade tiles sane -- the
    // fusion dt-clamp makes the vario respond ~5x faster per wall-second
    // at this cadence than at 1 Hz.
    static const uint16_t IMU_Read_Period = 100;
    static const uint16_t DPS_Read_Period = 1000;
    static const uint16_t RTC_Read_Period = 950;

    LSM6DS3* _myIMU;
    #if DS3231
        RTC_DS3231 _rtc;
    #else
        PCF85063A _rtc;
    #endif

    Dps3xx _dps;
    
    uint32_t lastDSPTime = 0, lastIMUTime = 0, lastRTCTime = 0, lastBATTime = 0;
    imu_data _imu;
    dps_data dps_dat;
    bool _dpsValid = false;

    float _f32_RTC_Temp;
    struct tm  _newDate;
    time_t _now;
    int16_t _nBattPercentage;
    bool _setTime = false;

    DPSCallback dpsCallback;
    IMUCallback imuCallback;

    // Measurement-frame stamping state (see HAL/Measurements.hpp)
    uint16_t _imuSeq = 0, _dpsSeq = 0, _rtcSeq = 0, _batSeq = 0;
    uint16_t _imuDtMs = 0, _dpsDtMs = 0, _rtcDtMs = 0, _batDtMs = 0;
    uint32_t _dpsOkTime = 0;    // millis() of last successful pressure/temperature fetch
    float    _vBatVolts = 0.0f;
    bool     _charging = false;

};

#endif /* SENSORS_H */

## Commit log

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2024-06-29 kicad libraries
    added symbols and footprints.
    put library files in dedicated folder
2024-06-29 Added PCB files
    added kicad project files
    [OBike.kicad_pcb, OBike.kicad_sch]
2024-06-29 fixing pcb references
    changed references to combined board to Obike in the PCB file
    [OBike.kicad_pcb]
2024-06-29 1.69" TFT
    Changed screen connections to suit an SPI screen
    Changed the arduino project to use the adafruit ST7789 library
    Intended LCD is the wavshare 1.69" LCD
    [OBike.kicad_pcb, OBike.kicad_sch]
2024-07-23 bugfixes
    fixed bug where speed available and cadence available where not set to 0 on csc begin
    added timer to main screen when logging
    seperated out devices init into seperate function that is only called if the wake interrupt has been triggered
    cadence now displayed as an integer
2024-07-24 fixed logging bug
    fixed bug that stopped data being written to log
    added functions to write tail data at the end of a log
    now calculate average and max speed
    using the sd card detection pin to reinit sd card when re-inserted
2024-08-05 bug fixes
    added lost power time reset for rtc
    changed device save file to json
    added delay after power on before loading devices from SD
    now wait a bit between connecting to multiple devices
    split draw method and ui method for BT screen
    bt devices now remain selected for storage
2024-08-07 batt disp
    added battery service to csc class
    added logging to sd card
    battery now displays on bt menu
    can now turn off obike by holding down button
2024-08-10 connection issue fix
    - fixed up scanning logic so start scan is not being called too often
    - connection and battery symbols only displayed for stored devices
    - stored symbol does not display for non stored devices
    - connection handle is stored for discovered devices
    - added disconnect callback
    - logger can now accept strings
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2024-08-18 BT device polymorphism
    Created base class of BT_Device
    csc now extends BT_Device
    created hrm class which extends BT_Device
2024-08-25 Bug fixing
    removing BT devices no longer causes crashes
    upped the number of data sources able to be logged
    changed most uses of String to char*
    heartrate now shows on main screen
2024-08-25 device scanning fixes
    scanning now starts for stored devices
    discovered devices now identified as the correct type
    hrm battery service now started correctly
2024-10-09 GPS code added
    just reading into variables and printing to console for now
2024-12-08 gps added
    [OBike.kicad_pcb, OBike.kicad_sch]
2025-01-15 gps 4-layer
    [OBike.kicad_pcb, OBike.kicad_sch]
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2025-01-31 removed list lib
    also fixed some GPS power stuff
2025-02-13 Added CPS notify
    also fixed some GPS power state stuff.
    added some flushes to the TPX logger to try and eliminate corruption
    [OBike_BOM.csv, OBike_BOM.xlsx]
2025-02-24 GPS power options
    - GPS settings menu, with save load to JSON on SD card
    - Ublox PM2 methods
    - UBlox GPS settings object
2025-05-08 stopper using logger
    also some fixes for tcx
    [OBike.kicad_pcb, OBike.kicad_sch]
2025-05-22 quectel module
    changed gps module
    increased board size
    moved gps module to front bottom left
    moved sd card front bottom right
    [OBike.kicad_pcb, OBike.kicad_sch]
2025-07-28 rev 3 pcb
    - quectel gps
    - u.fl antenae conn
    - aux power switch
    - flash chip
    [OBike.kicad_pcb, OBike.kicad_sch]
2025-08-17 rev 3 pcb
    [2025-08-17T012536.csv, OBike.csv, OBike_BOM.csv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]
2025-09-16 Purchased PCBs
    [OBike.kicad_pcb, OBike.kicad_sch]
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2025-10-25 migrate to platform IO
    [OBike.kicad_pcb, OBike.kicad_sch]
2025-11-04 BT device discovery
    - bt device system correctly starting in boot
    - added some debug messages
    - BT_Device::discovered function correctly overriden by children
    [App.cpp, main.cpp]
2025-11-06 LCD interface
    fixed mistakes in FPC connector nets
    [OBike.kicad_pcb, OBike.kicad_sch]
2025-11-15 lots of ui fixes
    [App.cpp, HAL.cpp, Sensors.hpp]
2025-11-16 more ui fixes
    starting to look ok
    [App.cpp]
2025-11-20 screen fpc
    - changed fpc to bottom mount pins
    - changed fpc footprint and symbol
    - updated fpc routing
    - added JST connectors for SPI & I2C expansion
    - stopped tracking kicad/*.zip
    [OBike.kicad_pcb, OBike.kicad_sch]
2025-11-25 better filtering for BT devices
    - also some ui fixes
    - added missing art
    - added GPS settings screen
    [App.cpp, main.cpp]
2025-12-08 pcb update
    [OBike.kicad_pcb, OBike.kicad_sch]
2025-12-14 BT fixes
    - BT screen now displays devices correctly
    - BT disconnect/connect from UI working
    - fixed missing break in APP DisconnectBluetooth event case
    - added lower and upper bound protection on Display flush
    - aux supply turns off when system sleeps
    [App.cpp, HAL.cpp, main.cpp]
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2025-12-14 GPS screen nav
    [OBike.kicad_pcb]
2025-12-15 fixed accumulating calcs
    - avg heartrate now more accurate (still not great)
    - avg cadence now more accurate (still not great)
    - telemetry now accumulates distance
    [App.cpp, App.hpp, HAL.cpp]
2025-12-16 Speed displays correctly
    If there was no other speed source the GPS speed would not get included in the speed average
    [HAL.cpp]
2025-12-16 BT sources removed on disconnect
    csc and hrm values of disconnected devices not used in average caluclations
2025-12-16 not all BT devices displayed
    missing update callback on BT load devices
2025-12-29 NMEA responses
    - HAL no longer has static members
    - LC76G class now manages NMEA sentences
    - LC76G class can fire callbacks when expected response seen
    - HAL no longer cares about LC76G state
    -
    [App.cpp, App.hpp, HAL.cpp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]
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2026-06-06 NMEA rates
    - fixed typo in NMEA rate messages
    - App now turns off all NMEA messages except RMC and GGA
    - added buffer protection to NMEA message access
    - main screen updates battery value
    - battery widget only invalidates on new value
    - reduced sensor update rates
    [App.cpp, App.hpp, HAL.cpp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]
2026-06-07 PCB speaker
    - buzzer now uses a header rather than SMD
    - added buzzer code to HAL
    - small fixes to tcx logger
    [OBike.kicad_pcb, OBike.kicad_sch]
2026-06-08 GPS screen update
    - all message type rates now accessible from GPS screen
    - fixed problem with erroneous button presses on startup
    - SD card detection state now used, detect insert and reload files
    - fixed compiler warnings
    - save NOVRAM now working
    [App.cpp, App.hpp, HAL.cpp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]
2026-06-09 schem updates
    - added locating holes for screen to PCB
    [OBike.kicad_pcb, OBike.kicad_sch]
2026-06-10 housing stl's
    [back_retainer_combo.stl, battery_strap.stl, housing.stl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]
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2026-06-10 GPS time sync
    - now read gpsTime on fix
    - if rtc time is too far from gps time, auto adjust RTC
    - UTC offset stored in biometrics.txt for now
    - updated readme with more deps too
    [App.cpp, App.hpp, HAL.cpp]
2026-06-11 updated part numbers
    [OBike.kicad_sch]
2026-06-11 fixed typo in part number fields
    [OBike.csv, OBike.kicad_sch, OBike.ods]
2026-06-11 zenners went EOL updated to new device
    [OBike.csv, OBike.kicad_pcb, OBike.kicad_sch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]
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2026-06-25 New duration widget
    - Durations now have a dedicated widget
    - fixed bug in csc where non update case was not accounted for
    - fixed small bug in TCX logger which caused negative lap times to briefly appear
    [HAL.cpp, Sensors.cpp]
2026-07-05 BT_Device updates
    bt devices no longer return vectors for their data, and clean up after themselves correctly
    [App.cpp, App.hpp, HAL.cpp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]
2026-07-10 bug fixes
    hrm conn_handle correctly assigned
    added grade to HAL
    reset distance on start logging
    [App.cpp, HAL.cpp]
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2026-07-31 Fix platformio.ini so the project builds from a clean checkout
    Two independent defects meant a fresh clone could not be compiled at all.
    1. `platform = Seeed Studio` is a display name, not a package identifier.
    Resolution failed before dependencies were even considered:
    UnknownPackageError: Could not find the package with
    'Seeed Studio' requirements
    The XIAO nRF52840 Sense board definition lives in Seeed's own platform
    repository, so point at it directly. The board id itself was correct.
    2. `lib_deps` continuation lines each began with "= ", so ConfigParser
    folded them into the value and PlatformIO saw seven entries literally
    named "= adafruit/RTClib" and so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
2026-07-31 Stop dropping NMEA sentences that straddle an I2C read boundary
    STATE_PROCESS_RECEIVE cleared _CR on entry:
    case STATE_PROCESS_RECEIVE:
    _CR = false;
    for(int i=0; i<_transactionLength;i++){
    _CR is a member precisely so it can carry across reads, and it needs to.
    Reads are capped at MAX_BUFFER (64) bytes while NMEA sentences routinely
    exceed that, so a sentence whose '\r' lands at the end of one read and
    '\n' at the start of the next failed the `if (_CR)` test in addSentence
    and was discarded. Longer sentences are hit disproportionately -- GSV in
    particular, which is why satellite data was the least reliable.
    The per-character `else _CR = false;` at the bottom of the loo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
2026-07-31 Bound the LC76G sentence framing buffers
    sendCommand framed the command body with sprintf into a buffer the same
    size as the source:
    char buffer[64];
    ...
    char buffer2[64];
    length = sprintf(buffer2, "$%s*%02X\r\n", buffer, checksum);
    The framing adds six characters plus a NUL, so a body anywhere near 64
    bytes overflows buffer2. Current commands are far shorter, so this was
    latent rather than live, but it is one longer PQTMCFG command away from
    being real.
    Two changes:
    - buffer2 is now sized from buffer (+8 for framing and NUL) rather than
    being an independent literal that has to be kept in sync by hand, and
    uses snprintf with a truncation check.
    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
2026-07-31 Validate BLE notification lengths before reading payload fields
    csc_notify and hrm_notify both took a uint16_t len and never used it,
    reading fixed offsets driven only by flag bits in data[0]. The payload
    comes from the remote sensor, so a short, truncated or malformed
    notification read past the end of the buffer.
    csc_notify memcpy'd 4+2 bytes on flag bit 0 and 2+2 on flag bit 1,
    from a buffer that could be a single byte
    hrm_notify read data[1] unconditionally, so a 1-byte notification
    was already out of bounds
    Each field is now bounds checked against len before it is read.
    Also range checks the body sensor location before using it as an array
    index: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
2026-07-31 Correct CSC rate arithmetic: 60*1024 constant and ms/tick conversion
    Three arithmetic errors in the speed and cadence rate calculations, found
    while writing the equivalent crank-revolution maths for the CPS profile.
    None of these are in the audit issue; they turned up during the fix.
    1. 61140 is not 60*1024.
    The comment says so explicitly -- "61140 is 60*1024, so this is
    converting the crank delta and time delta into revolutions per minute"
    -- but 60*1024 is 61440. A digit transposition, in all four places the
    constant appears. Cadence and wheel RPM both read 0.49% low, and so
    therefore does speed, since App::updateTelemetry derives it from
    wheel RPM.
    2. csc::update() ap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
2026-07-31 Fix buffer overflow reading device names from devices.txt
    loadDevices passed the SOURCE length to toCharArray rather than the
    destination capacity:
    device["name"].as<String>()
    .toCharArray(newDevice.name, device["name"].as<String>().length() + 1);
    newDevice.name is char[32]. devices.txt is a plain-text file on the SD
    card that a user can edit, and BLE device names are frequently longer
    than 31 characters, so any such name wrote past the end of the field and
    on through the rest of the struct -- MAC, batt, type, connected, saved --
    and beyond. Passing sizeof(newDevice.name) makes toCharArray truncate and
    NUL-terminate instead.
    scan_discovery had a milder version of the same prob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
2026-07-31 Populate the ambient temperature reading
    HAL::f32_temp was declared and returned by getTemperature(), and never
    assigned anywhere in the codebase -- grep finds exactly two references,
    the declaration and the getter. HAL is a function-local static, so the
    value was a clean zero rather than garbage, which is why a permanently
    0 C reading looked plausible rather than obviously broken.
    Both real sources were already being sampled and then dropped:
    _f32_RTC_Temp <- DS3231, Sensors.cpp:46
    dps_dat.f32_DSP_Temp <- DPS368, Sensors.cpp:70
    The plumbing from SensorSystem through to HAL::f32_temp was simply never
    connected. Prefers the DPS368 when it has a valid sample, falling back to
    the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
    [HAL.cpp]
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2026-07-31 Convert accelerometer reading from g to m/s^2 before integrating
    altitudeIMUUpdate subtracted standard gravity from a value expressed in
    multiples of standard gravity:
    float linear_acc_z = accZ - 9.80665f - acc_bias_z;
    LSM6DS3::readFloatAccelZ() returns g, not m/s^2 -- confirmed in the
    library source, where calcAccel is
    (float)input * 0.061 * (settings.accelRange >> 1) / 1000
    i.e. the mg/LSB sensitivity divided by 1000. So at rest this computed
    1.0 - 9.81 = -8.81 m/s^2 of fictitious downward acceleration and fed it
    straight into the velocity integrator.
    The barometer correction absorbs most of the resulting drift into
    acc_bias_z over the first few seconds, which is why altitude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
2026-07-31 Default wheel circumference and stop it suppressing the GPS fallback
    BikeData had no member initialisers and is value-initialised via
    `BikeData _data{}`, so wheelCircumference was 0 until /bikeStats.txt was
    loaded. App::updateTelemetry then did:
    if (wheelRPM.live) {
    speed = wheelRPM.value * circumference * 0.00006; // 0
    } else if (gpsSpeed.live) {
    speed = gpsSpeed.value; // skipped
    wheelRPM.live is true whenever a CSC sensor is connected, so on a device
    with no bikeStats.txt the first branch was taken, produced exactly zero,
    and prevented the GPS fallback from ever running. The display read
    0 km/h while moving, with a connected an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
    [App.cpp]
2026-07-31 Fix GPS to RTC time sync, which only worked at UTC+0
    The offset was applied in the wrong unit, to a field that should not have
    had an offset applied at all:
    _gpsNow = {rtcNow.year(), rtcNow.month(), rtcNow.day(),
    (uint8_t)((int)gpsNow.hour()+UTCoffset*60),
    gpsNow.minute(), gpsNow.second()};
    timeData::_offset is in minutes -- the declaration says so, to_local() adds
    it to the minute field, and TimeEditScreen steps it by 30 and displays
    offset()/60.0. Multiplying by 60 scales it by 3600x, and the result is
    then truncated to uint8_t:
    offset hour+offset*60 (uint8_t) valid hour?
    UTC+0 12 12 12 yes
    UTC+10 1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
    [App.cpp]
2026-07-31 Clamp layout rows and columns when loading from disk
    MainScreen::onEnter computes its grid pitch by dividing by both values:
    int _colPitch = (240)/_cols;
    int _rowPitch = (240)/_rows;
    with no guard. They come straight from the model, and App::loadLayout
    read them with `jsonBuffer["rows"]`, which yields 0 for a missing or
    unparseable key. A truncated or hand-edited layout.txt therefore divided
    by zero on the main screen.
    DisplayEditScreen already defended itself with constrain(l.rows, 2, 5);
    MainScreen did not. Rather than add a second local guard, this clamps at
    the point the data enters the model, so every consumer can rely on the
    invariant. The bounds move to named constants in L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
    [App.cpp]
2026-07-31 Handle file open failures and normalise settings paths
    Three related problems in the settings load/save paths.
    Open failures were never checked. Every save did:
    if (_storage->exists("/layout.txt")) _storage->remove("/layout.txt");
    File32 dataFile = _storage->openFile("/layout.txt", FILE_WRITE);
    serializeJson(doc, dataFile);
    SDCardSystem::openFile returns a default-constructed File32 when open()
    fails, so on failure this serialised into a closed file and silently did
    nothing. Note the ordering: the existing file is deleted first, so a
    failed reopen lost the previous settings as well as the new ones. The
    loads had the same gap, and additionally discarded the
    DeserializationError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
    [App.cpp]
2026-07-31 Convert speed to m/s when logging: rides were recorded 3.6x too fast
    Trackpoint::speed was documented as metres per second:
    double speed; // Optional: Instantaneous speed in meters per second
    but App::update passes Telemetry::speed, which is km/h -- the field is
    commented as such, and App::updateTelemetry derives it with
    speed = wheelRPM.value * circumference * 0.00006; // mm*rpm -> km/h
    FITLogger then encoded that value into the FIT `speed` field, which is
    m/s at scale 1000:
    _writer.writeU16(static_cast<uint16_t>(tp.speed * 1000.0));
    So a 30 km/h ride was recorded as 108 km/h. The same error was in
    `max_speed` on the lap message, and in the TCX logger's TPX <Speed> and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
2026-07-31 Make the Bluetooth device list scroll, and guard ListView on empty
    BluetoothScreen::moveSelection could never scroll:
    if (_selectedIndex<_scrollOffset+visibleDevices && _scrollOffset<0) {
    _scrollOffset is uint32_t, so `_scrollOffset < 0` is always false and the
    entire body was unreachable -- devices past the fourth could not be
    reached. -Wtype-limits flags it directly. The dead body would also have
    underflowed `_devices.size()-visibleDevices` whenever there were fewer
    devices than visible slots, had it ever run.
    Replaced with the standard keep-selection-visible clamp, matching what
    ListView::clampScroll already does.
    Two ListView fixes alongside it:
    - removeItem added the removed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
2026-07-31 Handle remaining switch cases and silence AppEvent payload warnings
    DisplayEditWidget::drawModeArrows omitted WidgetSubMode::DELETE and DONE.
    Neither takes a direction so neither should draw arrows, and the fall
    through was almost certainly intentional -- but writing them out keeps
    -Wswitch useful if a mode is added later.
    The -Wmissing-field-initializers warnings on AppEvent::payload are benign:
    the payload is a std::variant, which default-constructs to int{0}, so the
    brace-init was already well defined. Passing 0 explicitly says so and
    keeps the flag's output free of noise that has to be re-triaged on every
    build.
    src/ui now compiles without warnings.
    Refs #3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
2026-07-31 Decimate the GPS breadcrumb track to 1 Hz
    appendPoint was called from update(), which App::update calls on every
    main-loop iteration, and appended whenever the position differed from the
    previous point at all. GPS fixes arrive at 1 Hz, so at best this stored
    the same fix repeatedly and at worst it stored floating-point jitter.
    Either way the 600-point buffer filled in seconds, so the "recent track"
    covered a few seconds of riding rather than the breadcrumb trail
    MapWidget is drawing.
    Now rejects points less than one second apart, matching the GNSS fix
    rate. 600 points is then ten minutes of trail.
    That also disposes of the O(n) erase(begin()) concern raised alongside
    this: it now runs at m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
2026-07-31 Project the GPS track in Web Mercator to match the map tiles
    The raster and the overlay drawn on top of it used different projections.
    Tiles are fetched in Web Mercator at an integer zoom level. project()
    placed the breadcrumb track and position dot using an equirectangular
    approximation instead:
    const double metersPerDegLat = 111132.0;
    const double metersPerDegLon = 111320.0 * cos(_centerLat * M_PI/180.0);
    outX = (int)(cx + (dxMeters / _metersPerPixel));
    Two independent errors followed. First, tiles exist only at integer
    zooms, so computeZoom rounds -- the raster's true resolution can differ
    from the requested _metersPerPixel by up to a factor of sqrt(2), while
    project() kept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
2026-07-31 Add a Windows launcher for the simulator
    run.sh is a bash script, which is not much use on the platform this project
    is developed on. run.bat does the same job from cmd.exe, PowerShell or a
    double-click:
    - locates the MinGW-w64 toolchain, and prints the winget command if it
    is missing rather than failing with a bare "g++ not found"
    - puts Git for Windows' usr\bin on PATH, since the Makefile recipes use
    mkdir -p and rm -rf, which cmd.exe does not provide
    - checks .pio/libdeps exists and explains why it is needed
    - builds, then forwards all arguments to the binary
    Verified from PowerShell with build/ deleted first, so the clean-build path
    is covered, and the PPM to PNG conver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
2026-07-31 Add SDL2 window frontend; silence the warnings it surfaced
    SDL2 support for the interactive frontend, plus fixes for the real defects
    the host compiler found once it was building the whole tree.
    Simulator:
    - The Makefile prefers an SDL2 SDK unpacked under third_party/, then
    sdl2-config, then a bare -lSDL2 probe, then falls back to headless.
    SDL2.dll is copied next to the binary so nothing needs to be on PATH.
    - Deliberately NOT linked with -mwindows. That produces a GUI subsystem
    binary with no console, which would discard the firmware's Serial
    output -- half the reason to run the simulator at all.
    - third_party/ is gitignored and fetched by tools/get-sdl2.{sh,bat}. I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
    [main.cpp]
2026-07-31 Fix runaway menu scrolling; add an input timing probe
    The menu stepped on almost every frame instead of the intended 10/s. Two
    distinct causes, one in the simulator and one in the firmware.
    SIMULATOR (the cause of the reported symptom)
    SimHAL::init did not set GPIOB3, which the real HAL::init does. InputSystem
    reads that pin back and reports it as the GPS-enable state, and main.cpp's
    loop() ends with
    if (!App::instance().getGpsEnableState()) {
    digitalWrite(D6, false);
    delay(200);
    NRF_POWER->SYSTEMOFF = 1;
    so every simulated iteration took the sleep path and burned 200 ms of
    simulated time. Measured directly: millis() advanced 205 ms per loop
    instead of 5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
    [SimHAL.cpp, main.cpp]
2026-07-31 Add a sample SD card; remove the input timing probe
    The simulator booted to an empty telemetry grid because a fresh sdcard/ has
    no layout.txt, so MainScreen::onEnter built zero tiles. That reads as a
    broken simulator rather than an unconfigured one.
    sample-sd/ holds a starting configuration, copied into sdcard/ on first run
    by both launchers. Existing cards are never overwritten, so anything
    changed inside the simulator survives.
    layout.txt 2x3 grid: full-width Speed, then Cadence/HeartRate and
    Power/TotalDist. x1/y1 are exclusive, matching what
    App::saveLayout writes and DisplayItem::insideGrid checks.
    bikeStats.txt 2105 mm wheel circumferenc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
    [main.cpp]
2026-08-02 log telemetry struct
    - change addTrackpoint to ingest Telemetry and TimeData objects
    [back_retainer_combo + support.stl]
2026-08-09 pcb fixes
    - WP and Hold pins on flash shorted to aux 3v3
    - added a 32.768khz crystal for the RTC
    - fixed wrong part numbers for Q1 & Q2
    [OBike.kicad_pcb, OBike.kicad_sch]
2026-08-09 pcb fixes
    - crystal footprint
    - pcb zip
2026-08-19 back retainer had holes in wrong spot
    [back_retainer_combo.stl, housing.stl]
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2026-09-03 ui updates
    - also disp reset working
    [OBike.kicad_pcb, OBike.kicad_sch]
